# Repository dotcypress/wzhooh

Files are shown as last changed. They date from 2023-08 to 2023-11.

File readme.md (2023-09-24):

# Wzhooh

Slot Car Lap Timer

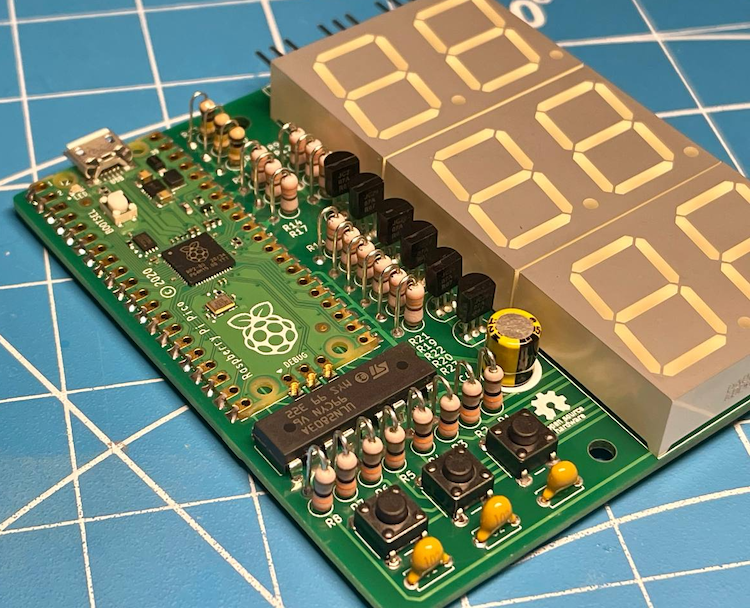
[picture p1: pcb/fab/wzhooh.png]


## Resources

- [Web dashboard](https://wzhooh.vercel.app)
- [Schematics](pcb/fab/wzhooh.pdf)
- [Gerber files](pcb/fab/Wzhooh_rev_0x01.zip)
- [BOM](pcb/fab/wzhooh-bom.csv)
- [Interactive BOM](https://htmlpreview.github.io/?https://github.com/dotcypress/wzhooh/blob/main/pcb/fab/ibom.html)

## Installation

1. Download latest firmware build from [Releases page](https://github.com/dotcypress/wzhooh/releases)
2. Hold the BOOTSEL button while connecting your board to the computer
3. Copy firmware file downloaded earlier to the RPi-RP2 disk
4. Enjoy

## Building firmware

1. Install rustup by following the instructions at https://rustup.rs
2. Install Cortex-M0, M0+, and M1 (ARMv6-M architecture) target: `rustup target add thumbv6m-none-eabi`
3. Install LLVM tools: `rustup component add llvm-tools-preview`
4. Install cargo-binutils: `cargo install cargo-binutils` (Note: on some Linux distros (e.g. Ubuntu) you may need to install the packages build-essential, gcc-arm-none-eabi, libssl-dev and pkg-config prior to installing cargo-binutils)
5. Install elf2uf2: `cargo install elf2uf2-rs`
6. Clone this repo: `git clone git@github.com:dotcypress/wzhooh.git && cd wzhooh`
7. Hold the BOOTSEL button while connecting your board to the computer
8. Flash microcontroller: `cargo run --release`

## License

Licensed under either of

- Apache License, Version 2.0 ([LICENSE-APACHE](LICENSE-APACHE) or
  http://www.apache.org/licenses/LICENSE-2.0)
- MIT license ([LICENSE-MIT](LICENSE-MIT) or http://opensource.org/licenses/MIT)

at your option.

### Contribution

Unless you explicitly state otherwise, any contribution intentionally submitted
for inclusion in the work by you, as defined in the Apache-2.0 license, shall be
dual licensed as above, without any additional terms or conditions.

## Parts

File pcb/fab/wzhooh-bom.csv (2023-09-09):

Id | Designator | Footprint | Quantity | Designation | Supplier and ref
1 | R11,R22,R20,R21,R14,R12,R9,R17,R19,R18,R23,R15 | R_Axial_DIN0207_L6.3mm_D2.5mm_P2.54mm_Vertical | 12 | 330Ω | https://m-teh.com.ua/ru/rezistor-330r-0.25w-cfr-5
2 | R4,R6,R8,R7,R5,R3,R2,R1 | R_Axial_DIN0207_L6.3mm_D2.5mm_P2.54mm_Vertical | 8 | 33Ω | https://m-teh.com.ua/ru/rezistor-33r-0.25w-cfr-5/
6 | C3,C1,C2 | C_Disc_D4.7mm_W2.5mm_P5.00mm | 3 | 1nF | https://m-teh.com.ua/ru/kondensator-mcc-0.1uf-50v-x7r-10/
7 | C4 | CP_Radial_D7.5mm_P2.50mm | 1 | 4.7uF | https://m-teh.com.ua/ru/kondensator-ze-330uf-10v-69-[polimerniy]/
8 | J1,J2,J3 | PinHeader_1x03_P2.54mm_Horizontal | 3 | Sensors | https://m-teh.com.ua/ru/pls1x40-zl201-40g/
9 | U4,U5,U3 | DA08-11 | 3 | DA08-11SURKWA | https://m-teh.com.ua/ru/indikator-2-rozryadi-0.8chervoniy-anod-chorniy-fon-kl-8021-bsr/
10 | R10,R16,R13 | R_Axial_DIN0207_L6.3mm_D2.5mm_P2.54mm_Vertical | 3 | 100KΩ | https://m-teh.com.ua/ru/rezistor-100k-0.25w-cfr-5
11 | Q3,Q1,Q2,Q4,Q6,Q5 | TO-92_Inline | 6 | 2N2907 | https://m-teh.com.ua/ru/tranzistor-2n2907/
12 | U2 | RPi_Pico_SMD_TH | 1 | Pico | https://arduino.ua/prod4358-raspberry-pi-pico
13 | SW1,SW2,SW3 | SW_PUSH_6mm_H13mm | 3 | Buttons | https://m-teh.com.ua/ru/knopka-taktova-tact-6x6-7.5
16 | U1 | DIP-18_W7.62mm | 1 | ULN2803A | https://m-teh.com.ua/ru/sborka-tranzystorov-uln2803apg

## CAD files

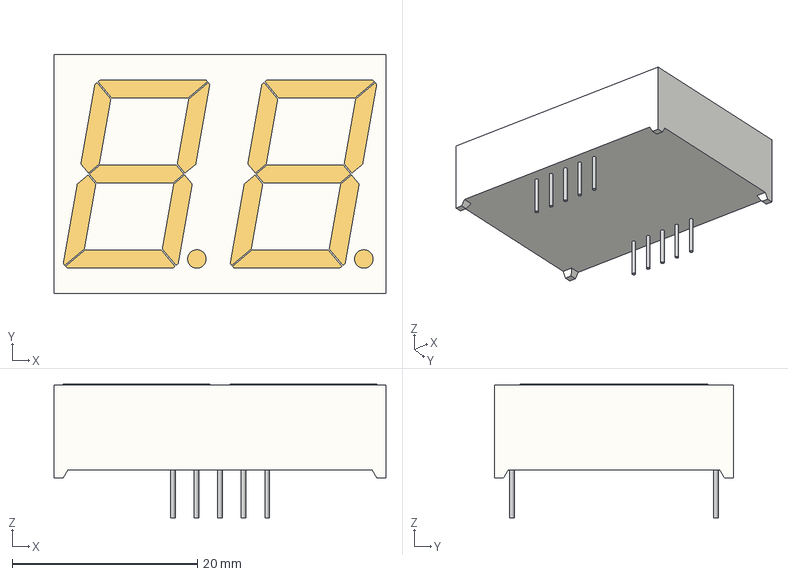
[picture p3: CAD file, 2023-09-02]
pcb/LED-08.step
35.8 x 25.8 x 14.4 mm

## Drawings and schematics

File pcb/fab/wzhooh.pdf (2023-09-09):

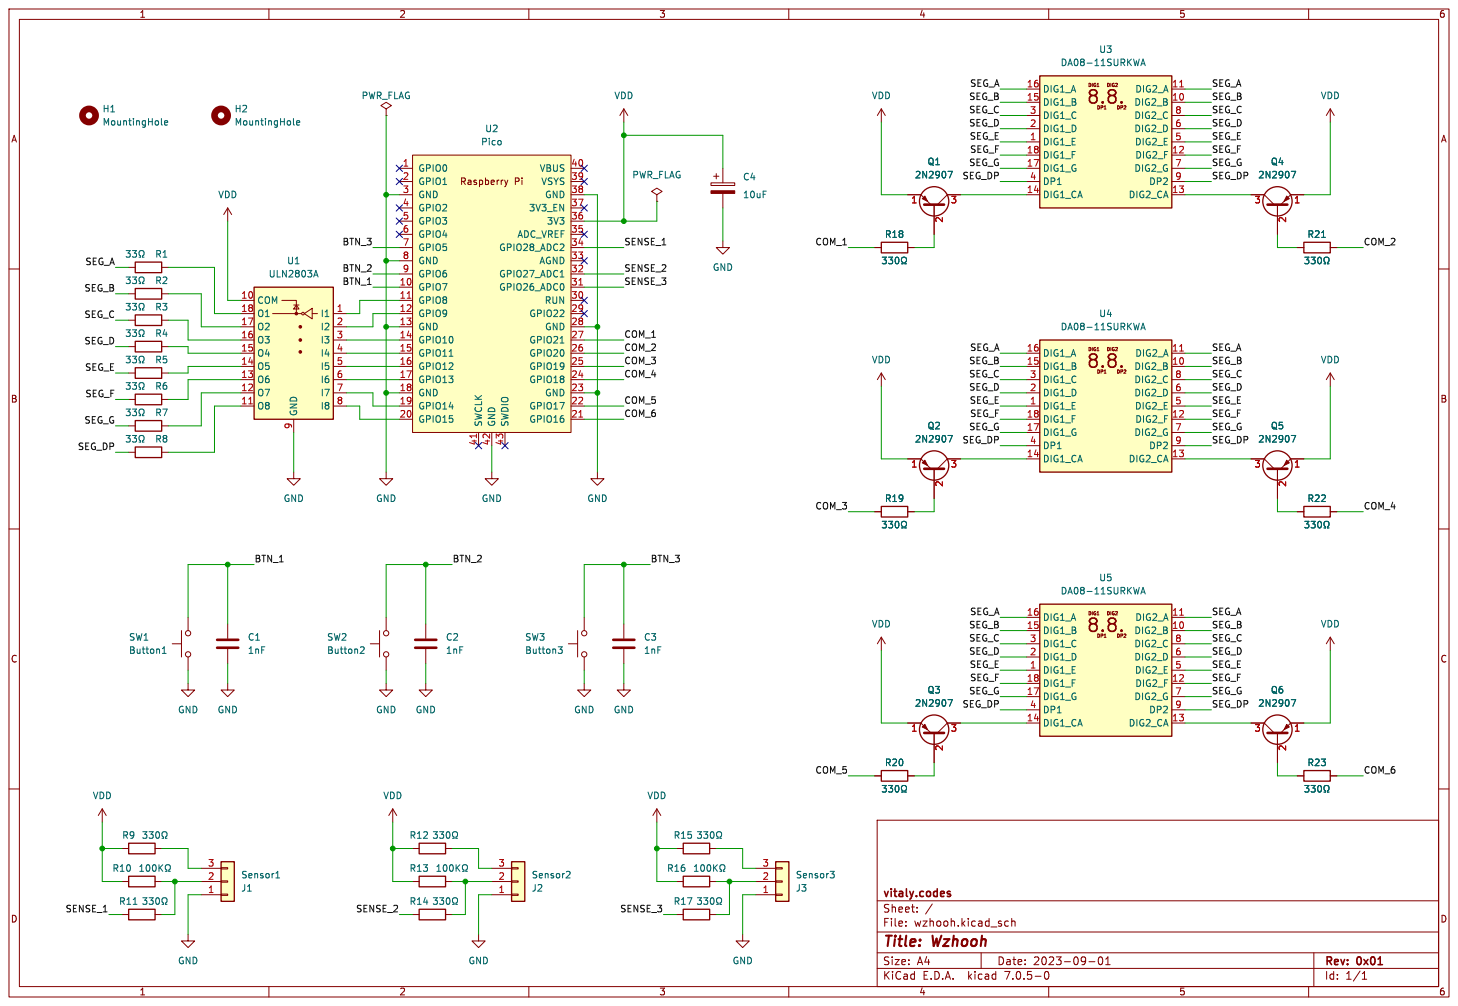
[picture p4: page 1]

File: wzhooh.kicad_sch Sheet: / vitaly.codes R9 þÿ330©

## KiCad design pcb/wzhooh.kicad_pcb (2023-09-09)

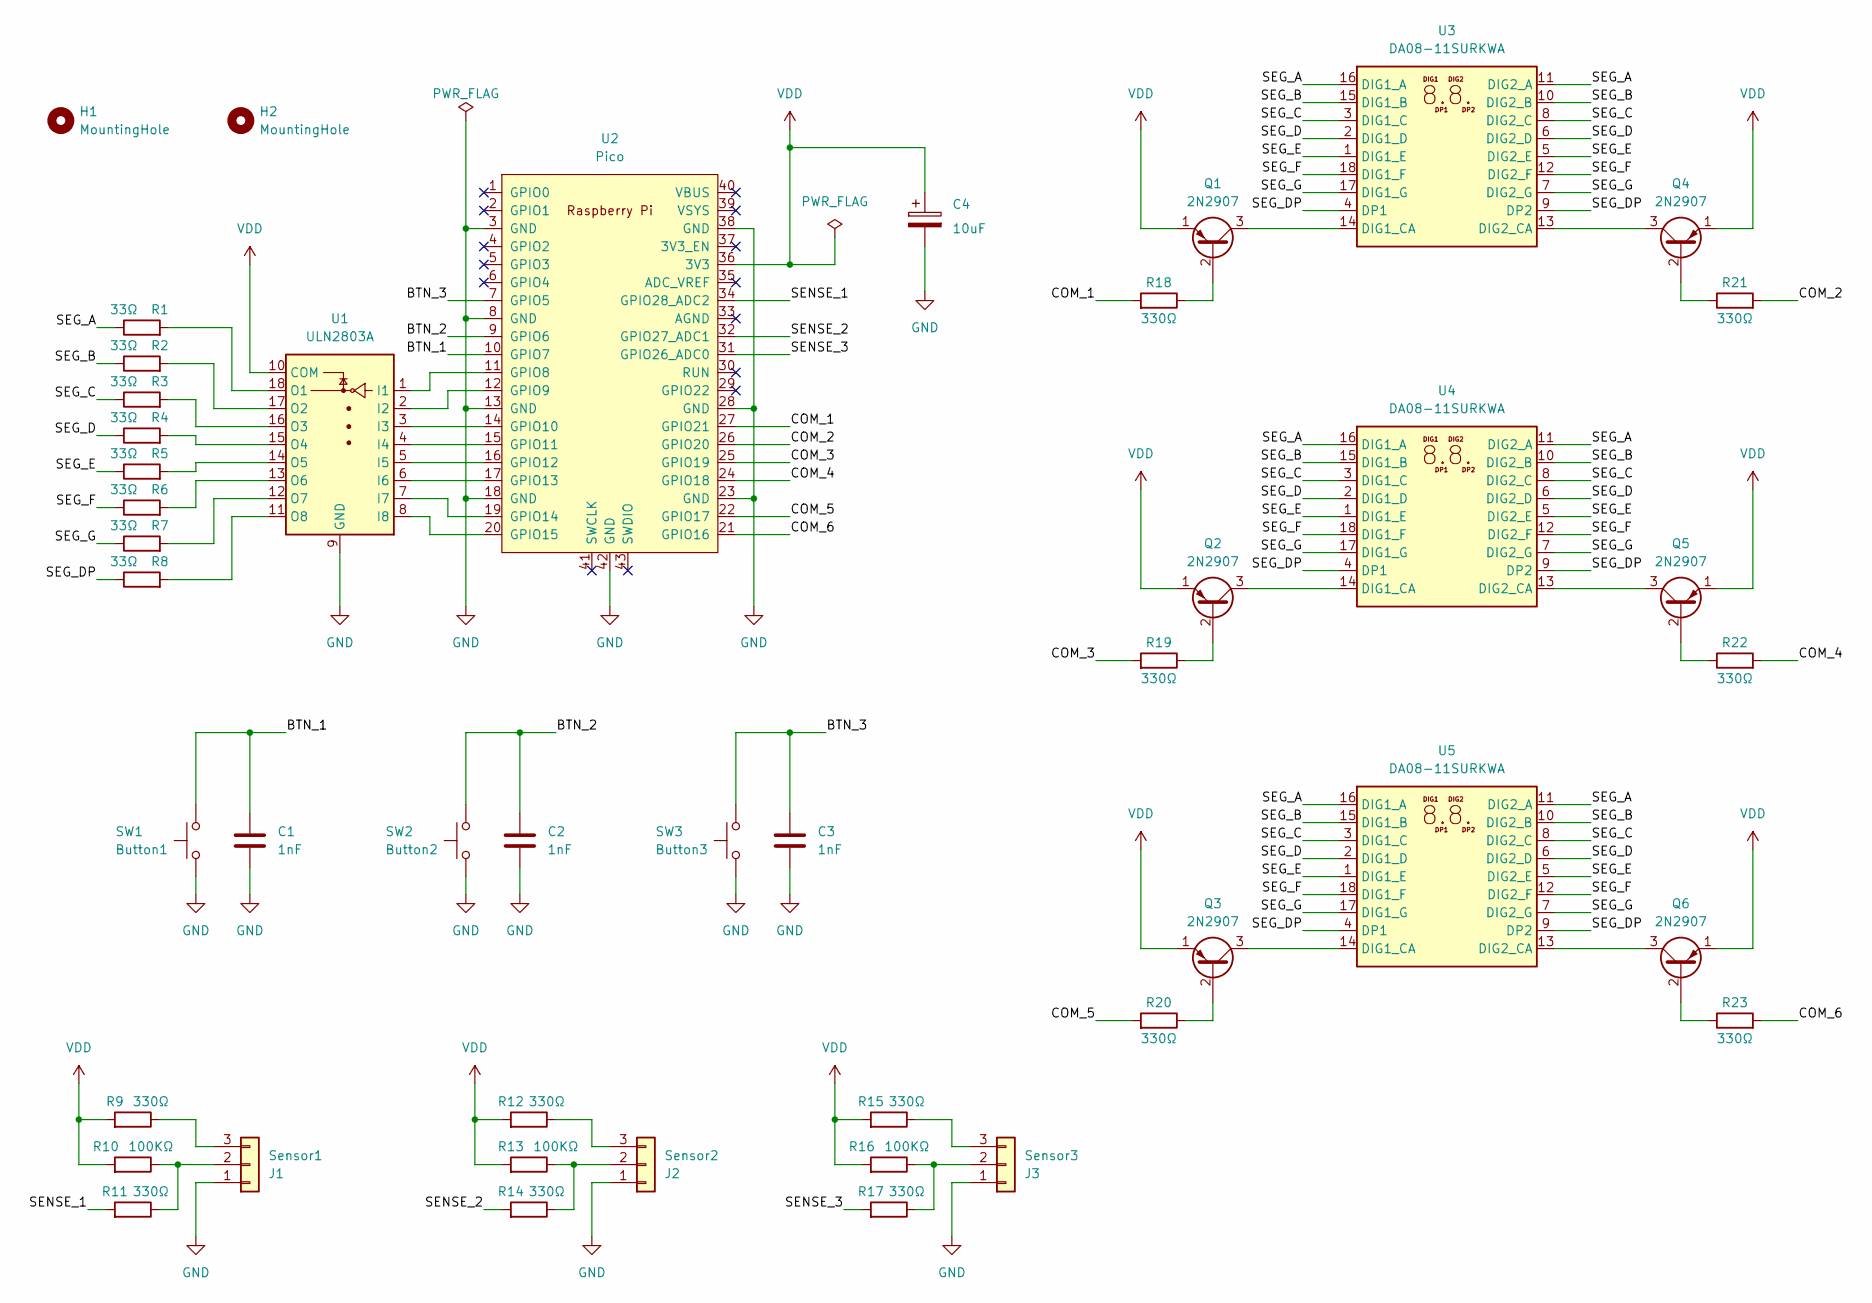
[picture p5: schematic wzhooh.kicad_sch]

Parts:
C1, C2, C3: 1nF; C_Disc_D4.7mm_W2.5mm_P5.00mm
C4: 10uF; CP_Radial_D7.5mm_P2.50mm
H1, H2: MountingHole; MountingHole_3.2mm_M3
J1: Sensor1; PinHeader_1x03_P2.54mm_Horizontal
J2: Sensor2; PinHeader_1x03_P2.54mm_Horizontal
J3: Sensor3; PinHeader_1x03_P2.54mm_Horizontal
Q1, Q2, Q3, Q4, Q5: 2N2907; TO-92_Inline
Q6: 2N2907; //www.mouser.com/datasheet/2/849/2n2907a-2577411.pdf
R1, R2, R3, R4, R5, R6, R7, R8: 33Ω; R_Axial_DIN0207_L6.3mm_D2.5mm_P2.54mm_Vertical
R9, R11, R12, R14, R15, R17, R18, R19, R20, R21, R22, R23: 330Ω; R_Axial_DIN0207_L6.3mm_D2.5mm_P2.54mm_Vertical
R10, R13, R16: 100KΩ; R_Axial_DIN0207_L6.3mm_D2.5mm_P2.54mm_Vertical
SW1: Button1; SW_PUSH_6mm_H13mm
SW2: Button2; SW_PUSH_6mm_H13mm
SW3: Button3; SW_PUSH_6mm_H13mm
U1: ULN2803A; DIP-18_W7.62mm
U2: Pico; RPi_Pico_SMD_TH
U3, U4, U5: DA08-11SURKWA; DA08-11

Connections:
/BTN_1: C1.1, SW1.2, U2.10 (GPIO7)
/BTN_2: C2.1, SW2.2, U2.9 (GPIO6)
/BTN_3: C3.1, SW3.2, U2.7 (GPIO5)
/COM_1: R18.2, U2.27 (GPIO21)
/COM_2: R21.2, U2.26 (GPIO20)
/COM_3: R19.2, U2.25 (GPIO19)
/COM_4: R22.2, U2.24 (GPIO18)
/COM_5: R20.2, U2.22 (GPIO17)
/COM_6: R23.2, U2.21 (GPIO16)
/SEG_A: R1.1, U3.11 (DIG2_A), U3.16 (DIG1_A), U4.11 (DIG2_A), U4.16 (DIG1_A), U5.11 (DIG2_A), U5.16 (DIG1_A)
/SEG_B: R2.1, U3.10 (DIG2_B), U3.15 (DIG1_B), U4.10 (DIG2_B), U4.15 (DIG1_B), U5.10 (DIG2_B), U5.15 (DIG1_B)
/SEG_C: R3.1, U3.3 (DIG1_C), U3.8 (DIG2_C), U4.3 (DIG1_C), U4.8 (DIG2_C), U5.3 (DIG1_C), U5.8 (DIG2_C)
/SEG_D: R4.1, U3.2 (DIG1_D), U3.6 (DIG2_D), U4.2 (DIG1_D), U4.6 (DIG2_D), U5.2 (DIG1_D), U5.6 (DIG2_D)
/SEG_DP: R8.1, U3.4 (DP1), U3.9 (DP2), U4.4 (DP1), U4.9 (DP2), U5.4 (DP1), U5.9 (DP2)
/SEG_E: R5.1, U3.1 (DIG1_E), U3.5 (DIG2_E), U4.1 (DIG1_E), U4.5 (DIG2_E), U5.1 (DIG1_E), U5.5 (DIG2_E)
/SEG_F: R6.1, U3.12 (DIG2_F), U3.18 (DIG1_F), U4.12 (DIG2_F), U4.18 (DIG1_F), U5.12 (DIG2_F), U5.18 (DIG1_F)
/SEG_G: R7.1, U3.7 (DIG2_G), U3.17 (DIG1_G), U4.7 (DIG2_G), U4.17 (DIG1_G), U5.7 (DIG2_G), U5.17 (DIG1_G)
/SENSE_1: R11.2, U2.34 (GPIO28_ADC2)
/SENSE_2: R14.2, U2.32 (GPIO27_ADC1)
/SENSE_3: R17.2, U2.31 (GPIO26_ADC0)
GND: C1.2, C2.2, C3.2, C4.2, J1.1, J2.1, J3.1, SW1.1, SW2.1, SW3.1, U1.9 (GND), U2.3 (GND), U2.8 (GND), U2.13 (GND), U2.18 (GND), U2.23 (GND), U2.28 (GND), U2.38 (GND), U2.42 (GND)
unnamed: J1.2, R10.1, R11.1
unnamed: J1.3, R9.1
unnamed: J2.2, R13.1, R14.1
unnamed: J2.3, R12.1
unnamed: J3.2, R16.1, R17.1
unnamed: J3.3, R15.1
unnamed: Q1.2 (B), R18.1
unnamed: Q1.3 (C), U3.14 (DIG1_CA)
unnamed: Q2.2 (B), R19.1
unnamed: Q2.3 (C), U4.14 (DIG1_CA)
unnamed: Q3.2 (B), R20.1
unnamed: Q3.3 (C), U5.14 (DIG1_CA)
unnamed: Q4.2 (B), R21.1
unnamed: Q4.3 (C), U3.13 (DIG2_CA)
unnamed: Q5.2 (B), R22.1
unnamed: Q5.3 (C), U4.13 (DIG2_CA)
unnamed: Q6.2 (B), R23.1
unnamed: Q6.3 (C), U5.13 (DIG2_CA)
unnamed: U1.1 (I1), U2.11 (GPIO8)
unnamed: U1.2 (I2), U2.12 (GPIO9)
unnamed: U1.3 (I3), U2.14 (GPIO10)
unnamed: U1.4 (I4), U2.15 (GPIO11)
unnamed: U1.5 (I5), U2.16 (GPIO12)
unnamed: U1.6 (I6), U2.17 (GPIO13)
unnamed: U1.7 (I7), U2.19 (GPIO14)
unnamed: U1.8 (I8), U2.20 (GPIO15)
unnamed: R1.2, U1.18 (O1)
unnamed: R2.2, U1.17 (O2)
unnamed: R3.2, U1.16 (O3)
unnamed: R4.2, U1.15 (O4)
unnamed: R5.2, U1.14 (O5)
unnamed: R6.2, U1.13 (O6)
unnamed: R7.2, U1.12 (O7)
unnamed: R8.2, U1.11 (O8)
VDD: C4.1, Q1.1 (E), Q2.1 (E), Q3.1 (E), Q4.1 (E), Q5.1 (E), Q6.1 (E), R9.2, R10.2, R12.2, R13.2, R15.2, R16.2, U1.10 (COM), U2.36 (3V3)

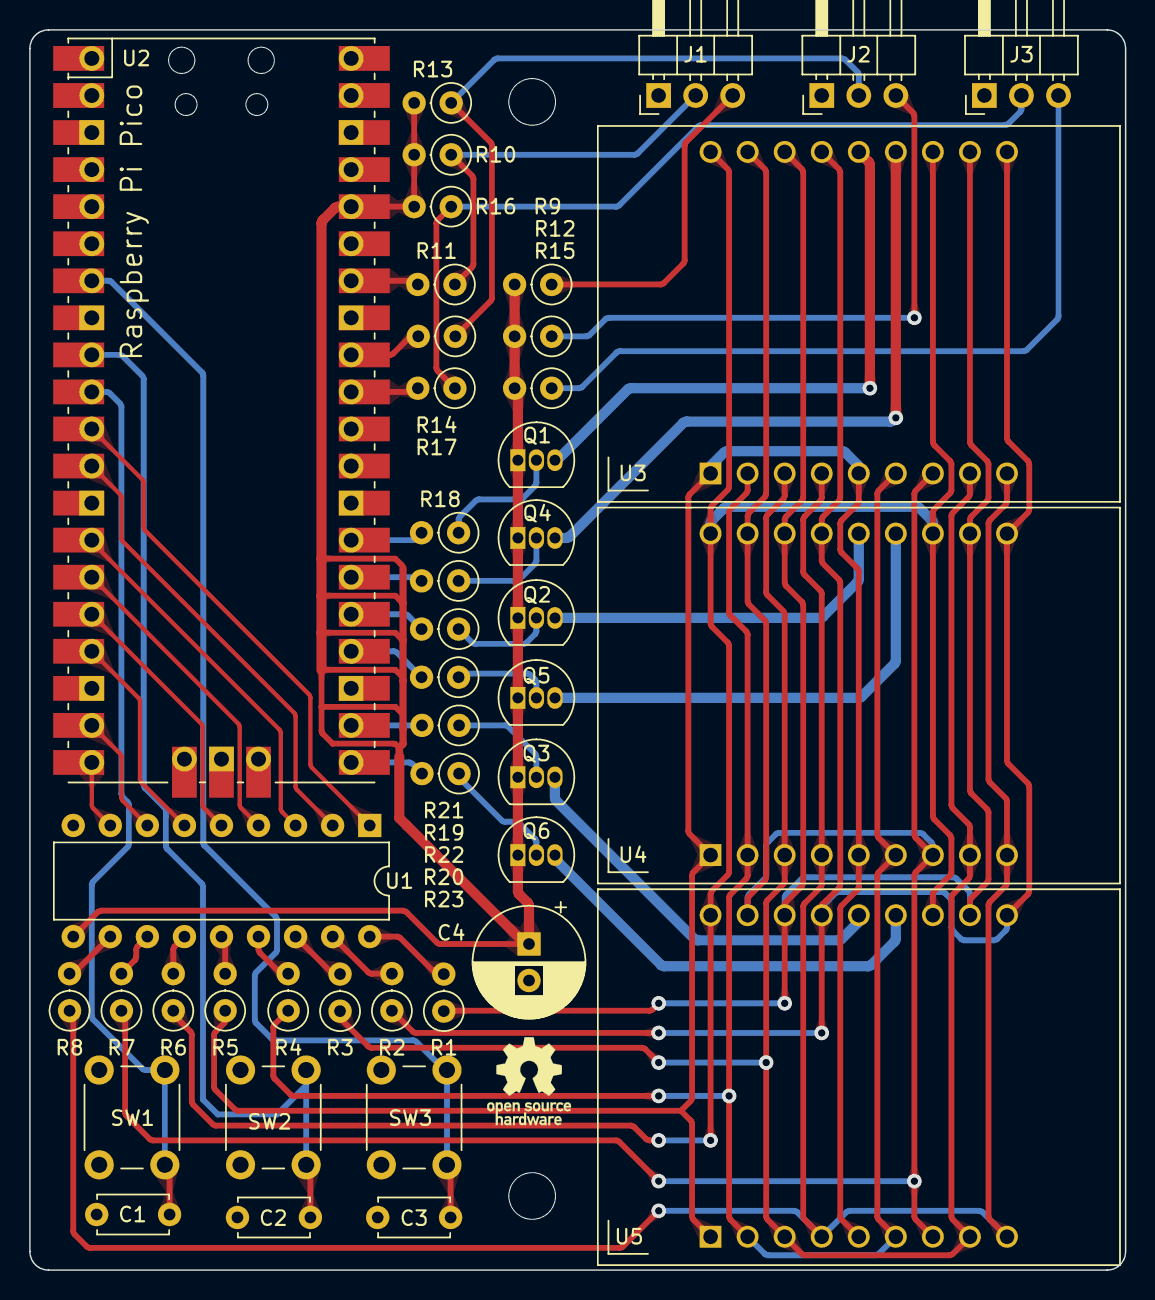
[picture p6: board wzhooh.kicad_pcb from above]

Board: 2 copper layers, 75.1 x 85.0 mm, 46 parts (0 on the bottom side), 56 nets.

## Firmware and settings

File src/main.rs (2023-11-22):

#![no_std]
#![no_main]

extern crate panic_probe;
extern crate rp2040_hal as hal;
extern crate rtic;

use defmt_rtt as _;

mod counter;
mod display;
mod io;
mod telemetry;

use cortex_m::singleton;
use counter::*;
use display::*;
use embedded_hal::digital::v2::OutputPin;
use hal::gpio::*;
use hal::pac;
use hal::pwm;
use hal::timer::{monotonic::Monotonic, *};
use hal::usb::UsbBus;
use io::*;
use telemetry::*;
use usb_device::class_prelude::*;
use usb_device::prelude::*;
use usbd_webusb::{url_scheme, WebUsb};

pub const XTAL_FREQ_HZ: u32 = 12_000_000_u32;

#[link_section = ".boot2"]
#[no_mangle]
#[used]
pub static BOOT2: [u8; 256] = rp2040_boot2::BOOT_LOADER_GENERIC_03H;

#[rtic::app(device = pac, peripherals = true, dispatchers = [SW0_IRQ, SW1_IRQ])]
mod app {
    use super::*;

    #[monotonic(binds = TIMER_IRQ_0, default = true)]
    type Oracle = Monotonic<Alarm0>;

    #[local]
    struct Local {
        buttons: Buttons,
        sensors: Sensors,
        ui_timer: pwm::Slice<pwm::Pwm0, pwm::FreeRunning>,
        usb_dev: UsbDevice<'static, hal::usb::UsbBus>,
        wusb: WebUsb<hal::usb::UsbBus>,
    }

    #[shared]
    struct Shared {
        display: Display,
        counter: LapCounter,
        telemetry: RaceTelemetryClass<'static, hal::usb::UsbBus>,
    }

    #[init]
    fn init(ctx: init::Context) -> (Shared, Local, init::Monotonics) {
        let mut resets = ctx.device.RESETS;
        let mut watchdog = hal::Watchdog::new(ctx.device.WATCHDOG);
        let clocks = hal::clocks::init_clocks_and_plls(
            XTAL_FREQ_HZ,
            ctx.device.XOSC,
            ctx.device.CLOCKS,
            ctx.device.PLL_SYS,
            ctx.device.PLL_USB,
            &mut resets,
            &mut watchdog,
        )
        .ok()
        .expect("Clocks init failed");

        let sio = hal::Sio::new(ctx.device.SIO);
        let pins = Pins::new(
            ctx.device.IO_BANK0,
            ctx.device.PADS_BANK0,
            sio.gpio_bank0,
            &mut resets,
        );

        let counter = LapCounter::default();

        let sensors = Sensors::new([
            pins.gpio28.into_floating_input().into_dyn_pin(),
            pins.gpio27.into_floating_input().into_dyn_pin(),
            pins.gpio26.into_floating_input().into_dyn_pin(),
        ]);

        let buttons = Buttons::new([
            pins.gpio7.into_pull_up_input().into_dyn_pin(),
            pins.gpio6.into_pull_up_input().into_dyn_pin(),
            pins.gpio5.into_pull_up_input().into_dyn_pin(),
        ]);

        let display = Display::new(
            [
                pins.gpio20.into_push_pull_output().into_dyn_pin(),
                pins.gpio21.into_push_pull_output().into_dyn_pin(),
                pins.gpio18.into_push_pull_output().into_dyn_pin(),
                pins.gpio19.into_push_pull_output().into_dyn_pin(),
                pins.gpio16.into_push_pull_output().into_dyn_pin(),
                pins.gpio17.into_push_pull_output().into_dyn_pin(),
            ],
            [
                pins.gpio8.into_push_pull_output().into_dyn_pin(),
                pins.gpio9.into_push_pull_output().into_dyn_pin(),
                pins.gpio10.into_push_pull_output().into_dyn_pin(),
                pins.gpio11.into_push_pull_output().into_dyn_pin(),
                pins.gpio12.into_push_pull_output().into_dyn_pin(),
                pins.gpio13.into_push_pull_output().into_dyn_pin(),
                pins.gpio14.into_push_pull_output().into_dyn_pin(),
                pins.gpio15.into_push_pull_output().into_dyn_pin(),
            ],
        );

        let pwm_slices = hal::pwm::Slices::new(ctx.device.PWM, &mut resets);
        let mut ui_timer = pwm_slices.pwm0;
        ui_timer.enable_interrupt();
        ui_timer.enable();

        let mut timer = hal::Timer::new(ctx.device.TIMER, &mut resets, &clocks);
        let alarm = timer.alarm_0().expect("Alarm0 init failed");
        let mono = Monotonic::new(timer, alarm);

        let usb_regs = ctx.device.USBCTRL_REGS;
        let usb_dpram = ctx.device.USBCTRL_DPRAM;
        let usb_bus = UsbBus::new(usb_regs, usb_dpram, clocks.usb_clock, true, &mut resets);
        let usb_bus: &'static UsbBusAllocator<UsbBus> =
            singleton!(: UsbBusAllocator<UsbBus> = UsbBusAllocator::new(usb_bus))
                .expect("USB init failed");

        let wusb = WebUsb::new(usb_bus, url_scheme::HTTPS, "wzhooh.vercel.app");
        let telemetry = RaceTelemetryClass::new(usb_bus);

        let usb_dev = UsbDeviceBuilder::new(usb_bus, UsbVidPid(0x1209, 0xb421))
            .manufacturer("vitaly.codes")
            .product("Wzhooh")
            .serial_number("_wzhooh_")
            .build();

        unsafe {
            pac::NVIC::unmask(pac::Interrupt::IO_IRQ_BANK0);
            pac::NVIC::unmask(pac::Interrupt::USBCTRL_IRQ);
        };

        (
            Shared {
                counter,
                display,
                telemetry,
            },
            Local {
                buttons,
                sensors,
                wusb,
                ui_timer,
                usb_dev,
            },
            init::Monotonics(mono),
        )
    }

    #[task(binds = IO_IRQ_BANK0, priority = 3, local = [buttons, sensors])]
    fn io_irq(ctx: io_irq::Context) {
        let now = monotonics::now();
        for track in 0..TRACKS {
            if ctx.local.sensors.is_car_detected(track) {
                io_event::spawn(IoEvent::CarDetected(track, now)).ok();
            }
        }
        for button in [Button::A, Button::B, Button::C] {
            if ctx.local.buttons.is_pressed(button) {
                io_event::spawn(IoEvent::ButtonPressed(button)).ok();
            }
        }
    }

    #[task(binds = USBCTRL_IRQ, priority = 2, local = [wusb, usb_dev], shared = [telemetry])]
    fn usb_irq(ctx: usb_irq::Context) {
        let mut telemetry = ctx.shared.telemetry;
        telemetry.lock(|telemetry| {
            if ctx.local.usb_dev.poll(&mut [ctx.local.wusb, telemetry]) {
                telemetry.send_report();
            }
            telemetry.app_req().map(app_req::spawn);
        });
    }

    #[task(binds = PWM_IRQ_WRAP, local = [ui_timer], shared = [display])]
    fn update_ui(mut ctx: update_ui::Context) {
        ctx.shared.display.lock(|display| display.animate());
        ctx.local.ui_timer.clear_interrupt();
    }

    #[task(capacity = 8, shared = [counter, display, telemetry])]
    fn app_req(ctx: app_req::Context, req: AppRequest) {
        let app_req::SharedResources {
            mut counter,
            mut display,
            mut telemetry,
        } = ctx.shared;

        match req {
            AppRequest::ResetCounter => {
                counter.lock(|counter| counter.reset());
                display.lock(|display| display.reset());
                telemetry.lock(|telemetry| telemetry.send_reset());
            }
            AppRequest::SendCounterState => {
                telemetry.lock(|telemetry| telemetry.send_reset());
                for track in 0..TRACKS {
                    if let Some(stats) = counter.lock(|counter| counter.stats(track)) {
                        telemetry.lock(|telemetry| telemetry.push_track_stats(stats))
                    }
                }
            }
        }
    }

    #[task(capacity = 16, shared = [counter, display, telemetry])]
    fn io_event(ctx: io_event::Context, ev: IoEvent) {
        let io_event::SharedResources {
            mut counter,
            mut display,
            mut telemetry,
        } = ctx.shared;

        match ev {
            IoEvent::CarDetected(track, ts) => {
                if let Some(stats) = counter.lock(|counter| counter.record_lap(track, ts)) {
                    display.lock(|display| display.set_track_laps(track, stats.laps()));
                    telemetry.lock(|telemetry| telemetry.push_track_stats(stats));
                }
            }
            IoEvent::ButtonPressed(_) => {
                app_req::spawn(AppRequest::ResetCounter).ok();
            }
        }
    }
}

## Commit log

2023-08-30 rename project
    [SlotCarLapTimer.kicad_sch, wzhooh.kicad_pcb, wzhooh.kicad_sch]
2023-09-02 pcb rev:0x01
    [LED-08.step, wzhooh.kicad_pcb, wzhooh.kicad_sch]
2023-09-06 add BOM
    [wzhooh-bom.csv, wzhooh.kicad_sch]
2023-09-09 rev: 0x01
    [wzhooh-bom.csv, wzhooh.kicad_pcb, wzhooh.kicad_sch]
2023-09-09 update pcb image
2023-11-18 switch to WebUSB
2023-11-18 fix counter reset bug
    [main.rs]
2023-11-19 update pid/vid
